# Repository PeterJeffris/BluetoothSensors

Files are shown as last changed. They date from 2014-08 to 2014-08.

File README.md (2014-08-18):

Background:
The goal of this project is to create an sensor platform wirelessly connected to a control and logging application on an android phone. The sensors include an accelerometer, a gyroscope, a combined barometer and temperature sensor and an ambient light sensor. The data is logged to the phones internal SD card or simply shown on the screen set with GUI configuration buttons on the android phone.

Software Development:
There are 3 collections of software developed for this project. The first is the java code for the android phone residing in the android folder. This code is intended to be compiled and uploaded to the phone using the android SDK package in the Eclipse IDE. This code contains a multithreaded android application that manages the display and configuration options in one group of threads and receives and processes and logs the data received over the Bluetooth radio connection in the other set.

The second collection of code is written in C++ and is used to run the Atmega328 chip that coordinates the collection of data from the sensors and is found in the AVR folder. This code is meant to be used with the wiring libraries and can be uploaded via the Arduino IDE or a build program such as scons or make. I2C driver libraries were written for this application to communicate with each of the sensors and are also included in this folder. Additionally there is a test script written in python that allows direct collection from the senor board by hooking up an FTDI cable to the Tx and Rx lines of the radio.

The final code is written in matlab and is used to determine the calibration coefficients for the relative alignment and scaling of the accelerometer and gyroscope. There are also several functions written to perform conversions between Euler angles which the gyroscope returns and rotation matrix and quaternion representations.

Hardware Development:
The circuit schematics and PCB layout are present in the hardware folder. These files are mean to be developed with the Eagle CAD software. The board itself is constructed as an Arduino compatible shield and matches directly with the pins on an Arduino board. Each of the sensors was purchased on breakout boards from sparkfun allowing for through hole construction techniques using chemically etched boards. 

A solder jumper had to be modified on the bottom of the gyroscope boards in order to change their output from SPI to I2C. Along with the gyroscope, the accelerometer and barometer also use the I2C communication protocol. Theses chips are placed on a single BUS with 3.3 Volt logic. This logic is then converted to 5 volt logic to the AVR processor using a level shifting circuit. The power supply utilizes 4 AA alkaline batteries whose voltage begins at 5.6 volts and drops to 4 volts at 4 discharge. The linear regulator supply filters and regulates this voltage at the cost of a 1 volt drop out. The AVR processor and radio are tolerant to the voltage changes down to the point where the batteries are operating at 4 volts. 

To configure the radio it must be connected to an FTDI cable. Open a serial terminal using the FTDI port (the arduino IDE serial monitor will also work if you select the FTDI port) and disable the line ending on output and send the string '$$$' (everything inside '' is entered and return is pressed). You will see the radio enter command mode by returning 'CMD' if you have done the setup correctly and the status light will blink at a faster interval. Then re-enable line endings and send the command 'SN,DEVICE_NAME' where DEVICE_NAME is what you want the bluetooth device name to be displayed as. Use the command 'SP,XXXX' to set the security pin where XXXX is the alphanumeric pin code to be entered upon connecting to the device from a phone. Use the command 'SU,XX' to set the baud rate where the XX is the first two characters of the baud rate (ie 11 -> 115000 bits per second). If this is done the corresponding baud rate in the AVR code also needs to be changed. To verify this information has been properly set use the 'D' command to display the basic settings. 

Features: 
The slides included in this repository describe the various features of the system and show the conclusions of the experimental trials utilizing the sensor.

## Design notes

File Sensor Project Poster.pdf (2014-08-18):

# Smartphone-Enabled Mobile Measurements

### Systems and IMU Research by Peter Jeffris Directed by Professor Y.C. Lee

## Overview

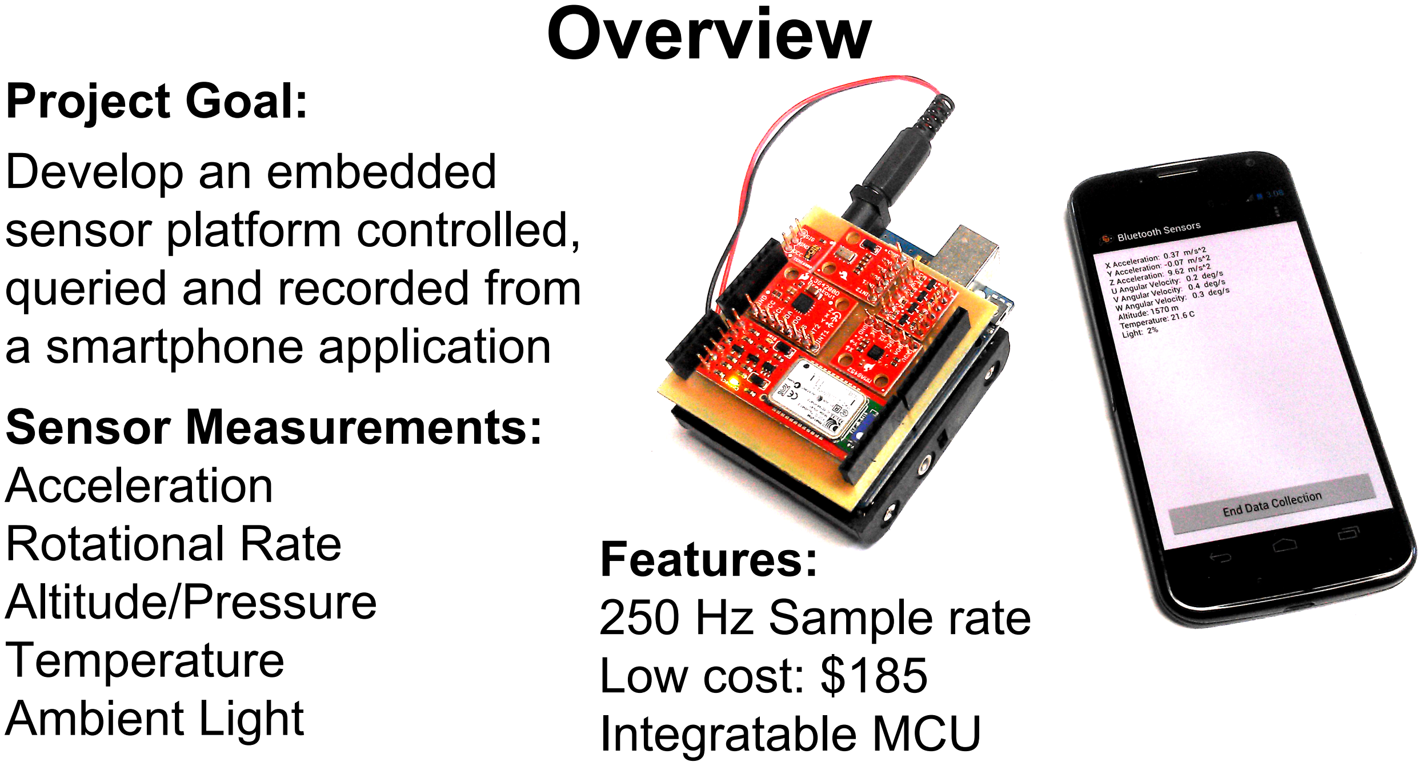
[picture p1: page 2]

Project Goal:
Develop an embedded
sensor platform controlled, queried and recorded from
a smartphone application
Sensor Measurements:
Acceleration
Rotational Rate
Altitude/Pressure
Temperature
Ambient Light

Features:
250 Hz Sample rate
Low cost: $185
Integratable MCU

## Systems Architecture

Logging Platform:
Motorola Moto X
running Android 4.4

Sensor Hardware:

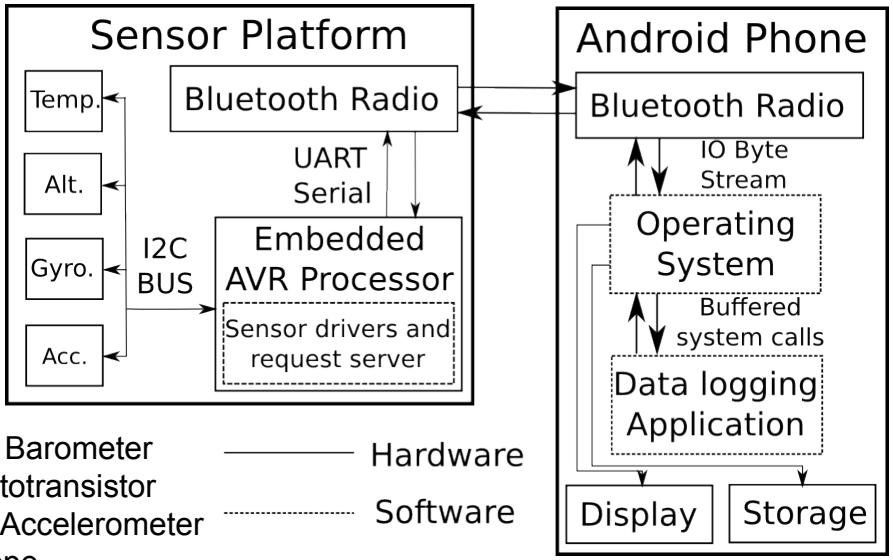
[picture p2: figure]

Freescale MPL3115A2 Barometer Vishay TEMT6000 Phototransistor Freescale MMA8452Q Accelerometer ST L3G4200D Gyroscope

Sensor Platform:
AVR microcontroller
and Arduino board
compatible sensor
shield powered by an
AA battery pack

## Android User Interface

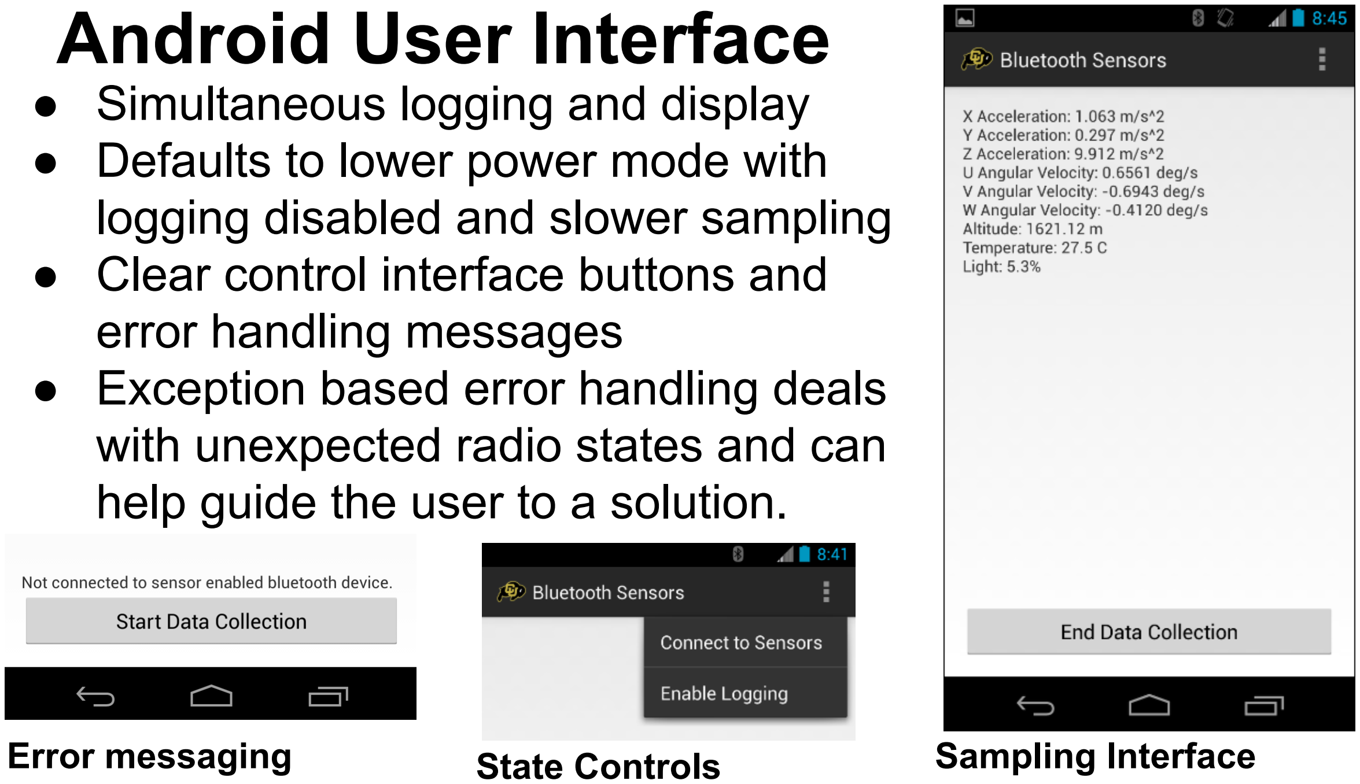
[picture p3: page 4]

- Simultaneous logging and display
- Defaults to lower power mode with logging disabled and slower sampling
- Clear control interface buttons and error handling messages
- Exception based error handling deals with unexpected radio states and can help guide the user to a solution.
Error messaging | State Controls | Sampling Interface

## Android Threading Methods

Multithreading:
Allows sensor data

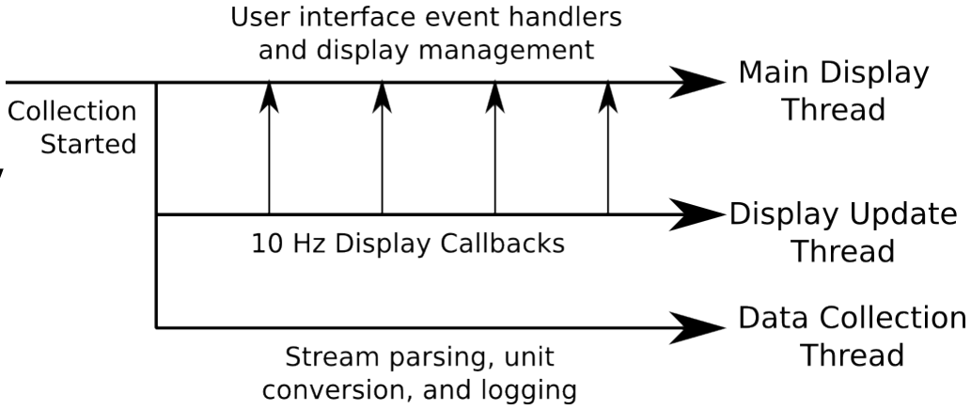
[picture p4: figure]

processing and display
synchronisation to be
handled by the
operating system
scheduler
This approach solves several problems:
1. Minimizing report latency and consistent display refreshing
2. Allows user interface to be responsive regardless of load
3. Reduces complexity of error handling and state changes

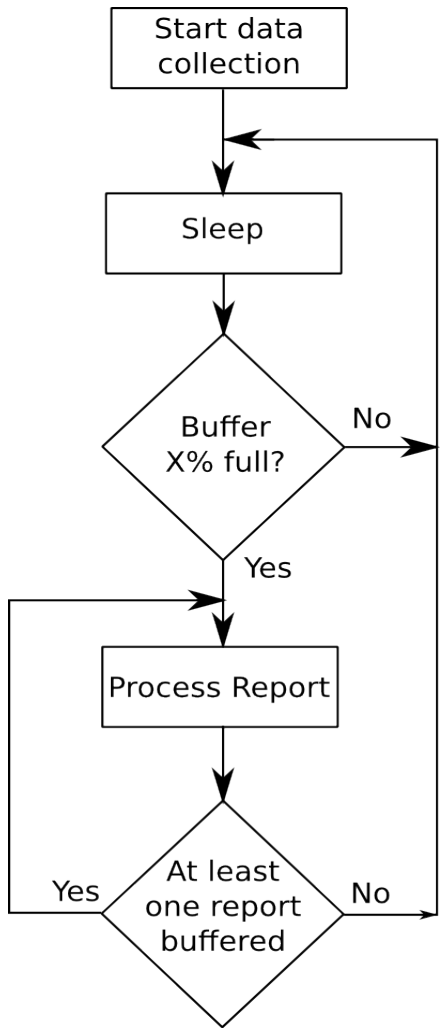
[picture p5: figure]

## Android Input/Output Methods

Buffered I/O Benefits:
- Reduced context switching overhead: Fewer system calls are required to read the stream
- Fast and efficient memory access: Large chunks of each memory page can be cached and processed quickly
Tuning:
- Single parameter for management of buffer overflow and report processing latency
- Buffer size set to maximize sampling with system memory and processing resources

## Networking Methods

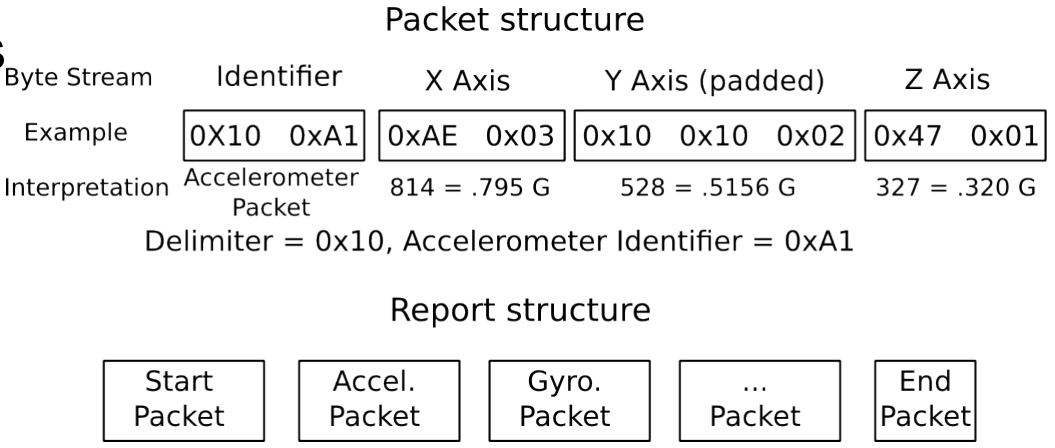
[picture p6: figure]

An single delimiter indicates a packet type while two delimiters indicates a payload byte that is identical to the delimiter itself

- Bluetooth Radio has
no QOS guarantees
- Packets structure
allows checking for
lost bytes, enabling
streaming reports
- Report Structure
simplifies correction
routine after a
corrupted packet

## Sensor Board Construction

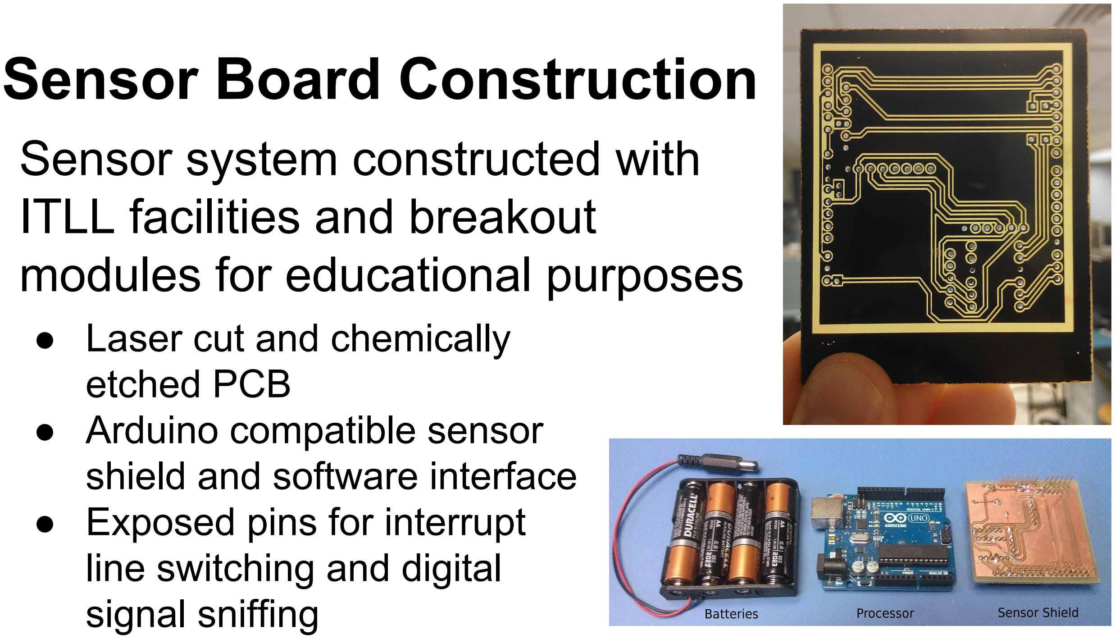
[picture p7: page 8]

### Sensor system constructed with ITLL facilities and breakout modules for educational purposes

- Laser cut and chemically
etched PCB
- Arduino compatible sensor
shield and software interface
- Exposed pins for interrupt line switching and digital signal sniffing

## Sensor Fusion

- Change in linear distance can be estimated by double
integrating acceleration with respect to time
- Gravity must be subtracted from the total acceleration and the result transformed into the earth’s reference frame
- The gyro is integrated to keep track of changes in attitude when the acceleration vector is greater than the gravity vector
- Information from both
sensors can be fused to
provide an estimate with
smaller uncertainty

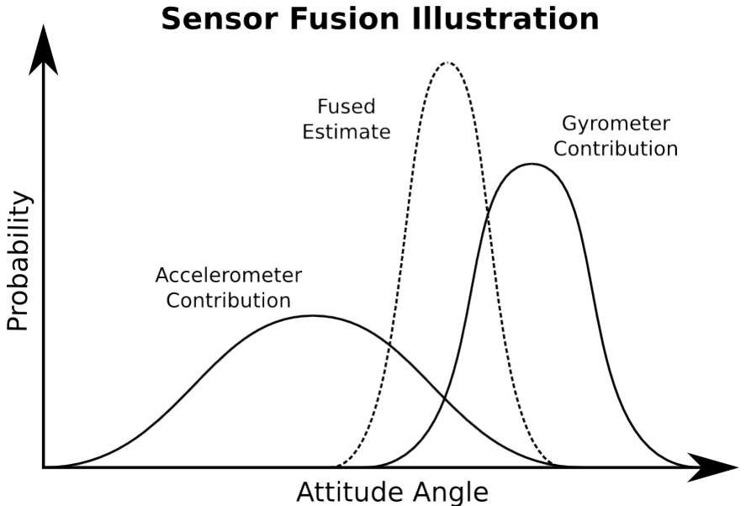
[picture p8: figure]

## Calibration and Filtering

Calibration Parameters

- Accelerometer and gyrometer reference frame alignment
- Accelerometer and gyrometer scale correction
- Accelerometer offset bias
Filtering Methods
- Kalman filtering optimally removes sensor noise from the position estimate
- Quaternion attitude representation prevents gimbal lock
- Runge-Kutta integration minimizes numerical integration error

Effective calibration and
filtering are required to
prevent integration drift

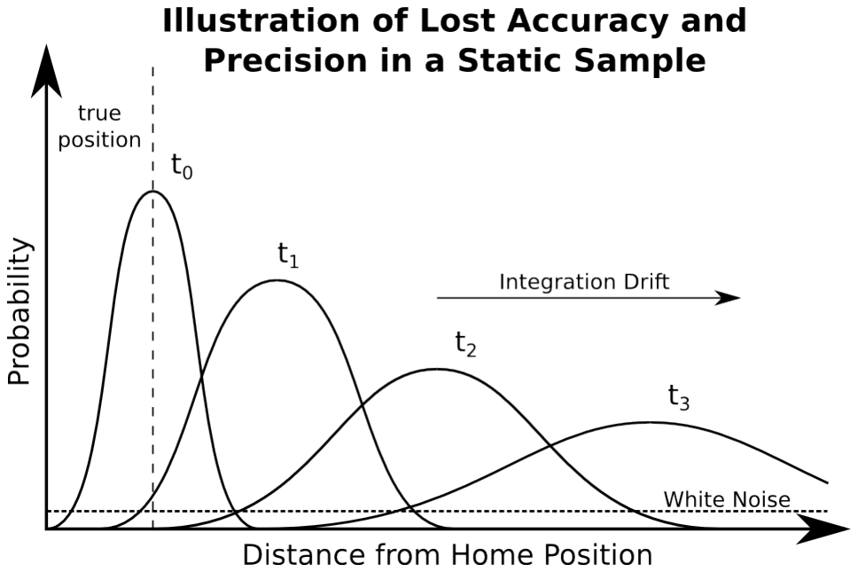
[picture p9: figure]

## Linear Testing

Test: Estimate of linear distance traveled

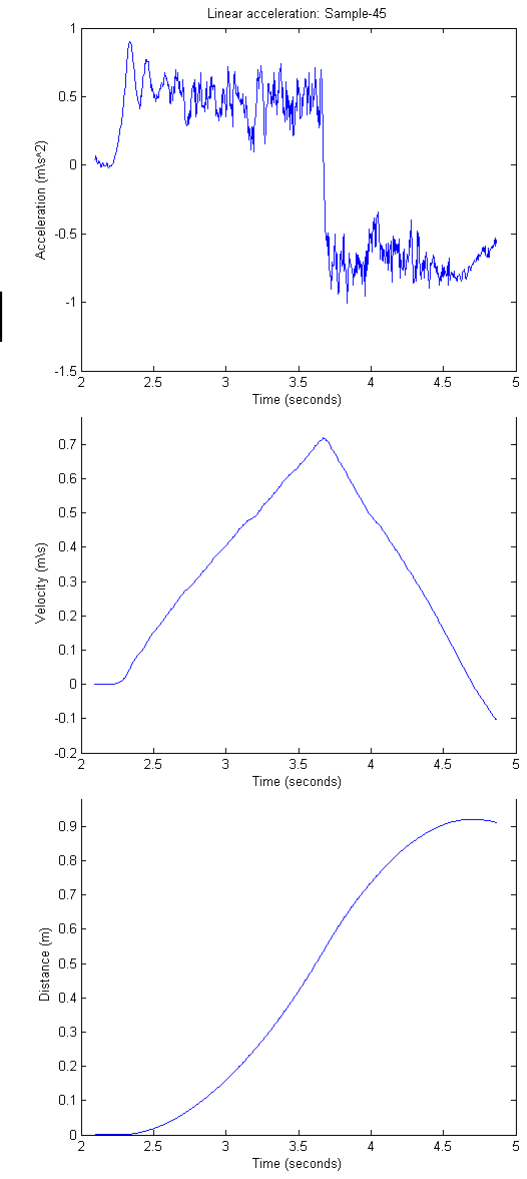
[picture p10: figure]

under step acceleration with simpsons method at various filter cutoff rates and sampling frequencies.
Results:
- Low pass filtering does not increase mean estimate accuracy
- Increased sampling speed increases mean estimate precision
- Bias offsets dominates the error if the sensors are not carefully calibrated

## Applications

Systems Integration

- Multitasked with other processes
- Real time motion analysis
- Live networked reporting
- Control system operation
- Example: Intel Galileo development board running a Linux OS

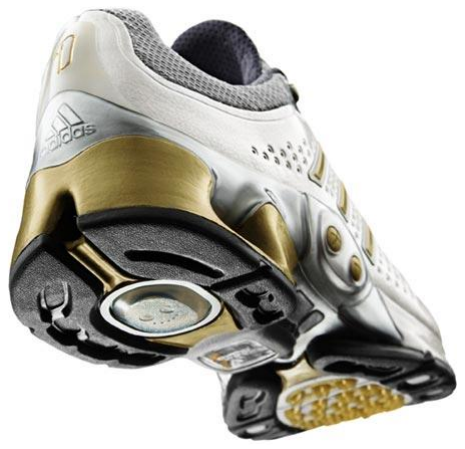
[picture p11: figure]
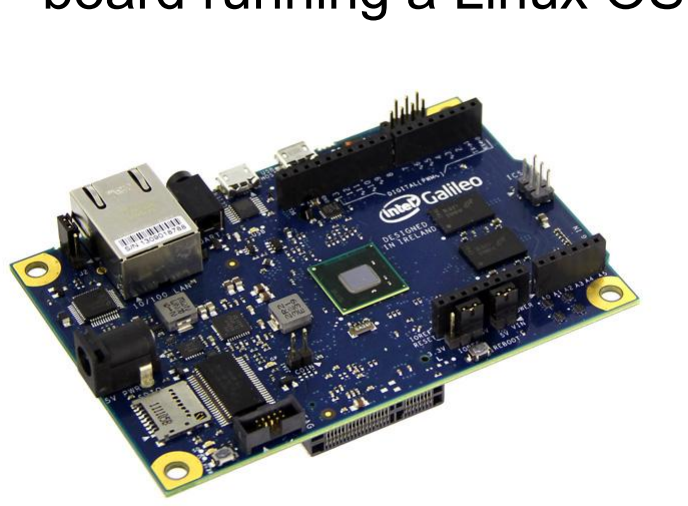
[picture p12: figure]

Embedded Sensors
- Wearable electronics
- Robot attitude
- Vehicle motion
- Slip detection

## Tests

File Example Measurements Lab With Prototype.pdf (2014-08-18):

# Position Estimation via Accelerometer Data

Introduction
Inertial sensors belong to a class of sensors that offer high precision indications of changes in kinematic state over short time periods. Other systems like GPS and GSM triangulation can offer relatively high accuracy in position but do not have high precision. Measurements of changes in the inertial frame of micromechanically machined capacitive sensors can be used to infer changes in position and in conjunction with the other location mechanisms can be used to achieve a highly precise and accuracy location mechanism. The application of numerical integration and gravity filtering techniques are critical to leveraging the inertial sensors accuracy. Using a sensor platform to record acceleration and angular rate, this lab will investigate the effects on filtering and sample rate on position estimates inferred from the inertial measurements.

Initial Tests
The main obstacle for obtaining position estimates from acceleration data is removing the effects of integration drift. Small bias in the acceleration data doubleintegrates large changes in position, even for stationary sensors. An obvious bias is gravity, which acts -9.8 1 constantly in the zdirection. Other
s

2

m
biases include zeromean signal noise in the acceleration data which develop a nonzero bias when digitally sampled. Several three dimensional test were performed in which the gravitational bias and initial orientation of the sensors with respect to gravity was found in a calibration period. The gyro and accelerometer measurements were then fused utilizing a rotation matrix to find the acceleration in gravities reverence frame. It was found that small errors in the estimate of the orientation caused by drift in the gyro resulted in large nonlinear drift in the acceleration due to the estimated orientation of the sensors being misaligned with gravity. This misalignment caused components of the gravity offset to be subtracted from the wrong axes resulting in steady state error in the perceived acceleration. Once this error was integrated twice large errors in position an order of magnitude large than actual movement were observed.

Experimental Setup
Since bias error corrupts the acceleration data, a repeatable experiment is implemented in order to analyze the errors and statistically predict which sampling frequencies and lowpass filtering produce the most accurate data. Our repeatable setup explores prediction accuracy with one dimensional stepped constant acceleration.

TABLE 1: EXPERIMENTAL FACTOR LEVELS

Factors | Lowpass filter cutoff | Sampling Rate
Level 1 | 20 Hz | 500 Hz
Level 2 | 10 Hz | 250 Hz
Level 3 | Infinite | 125 Hz

A linear rail isolates motion of the sensor to a single axis, see Figure 5. A lowfriction cart, with the sensor clamped onto it, accelerates constantly by a falling bolt which is tethered to the cart by a string. The track is slightly inclined so there is a period of constant acceleration while the bolt falls and another period of constant acceleration in the opposite direction after the bolt hits the ground, see Figure 6. Before each trial, the cart is left still to record calibration data of the components of gravity present in each sensor axis. The sensor platform logs the values to delimited file via a serial connection. The experiment has two factors: hardware lowpass filter cutoff frequency and sampling frequency with three levels each as seen in Table
1. Each treatment application is randomly applied in order to minimize a consistent effects from uncontrollable factors.

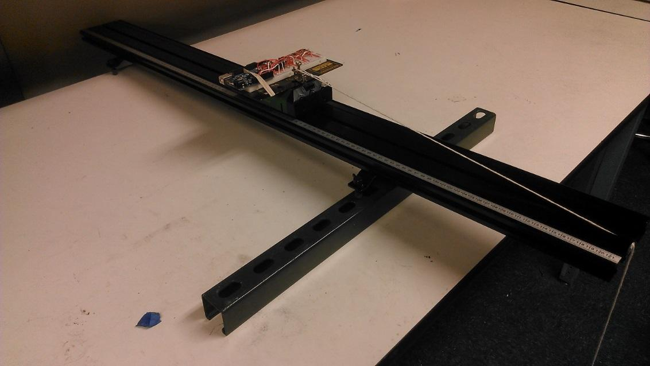
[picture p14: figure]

FIGURE 1: LINEAR RAIL EXPERIMENTAL SETUP

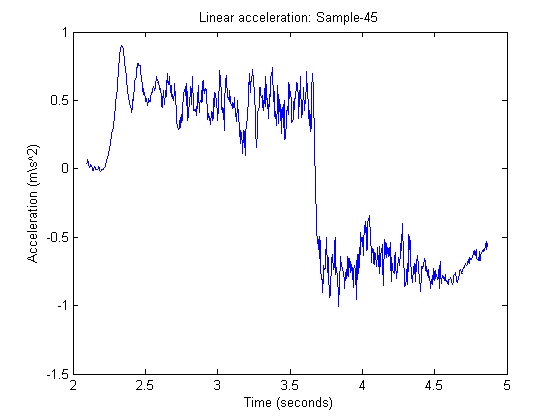
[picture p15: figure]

FIGURE 2: SAMPLED CONSTANT ACCELERATION AND DECELERATION

Materials
MMA8452Q 3-Axis Accelerometer | Arduino Uno
Breadboard and Wiring | Weight
Low-Friction Track (120cm) | Twine
Low-Friction Cart | Matlab
Clamp | Temperature sensor

Trial Procedure
A sensor board is constructed with a MMA8452Q 3-Axis accelerometer on an I2C bus connected to an 8 bit Atmel 328 microcontroller. Data is relayed from the sensor to a computer via a USART serial connection and stored in a csv format with each accelerometer axis as produced by the on board analog to digital converter and the time recorded between samples in microseconds. The cart is first placed on an inclined track and the sensor board is clamped down to the cart. The initial temperature is recorded and the position of the front of the cart is measured from the linear scale on the track to +/.5mm.
Acceleration of the cart is achieved by attaching a string between the cart and a weight. When the weight is dropped it would overcome gravity and accelerate until it hit the ground ending the forward acceleration step. Then gravitational acceleration would cause a step of negative acceleration for the remainder of the test. A piece of paper folded into a triangle is placed 3 centimeters before the predicted end point along the scale as seen in Figure 8. The cart would hit this triangle and push it up to the maximum distance, from which the actual maximum distance traveled could be found to a precision of +/.5mm. For each test a small calibration is performed with a three second delay, then the weight is moved near to the point where it would start supporting the weight of the cart and dropped. When the cart has reached its maximum distance traveled it is allowed to slide back for a second before being caught and ending data collection.

The treatments are applied randomly based on ordered numbers generated by a computer pseudo random number generator in Matlab. At the end of the test the temperature is measured again.

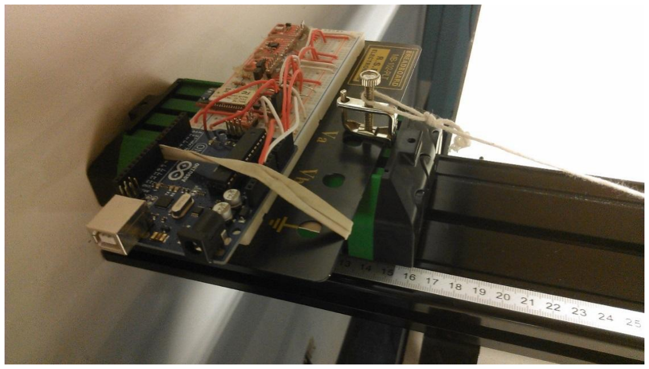
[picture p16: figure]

FIGURE 3: ACCELERATION MODULE SETUP

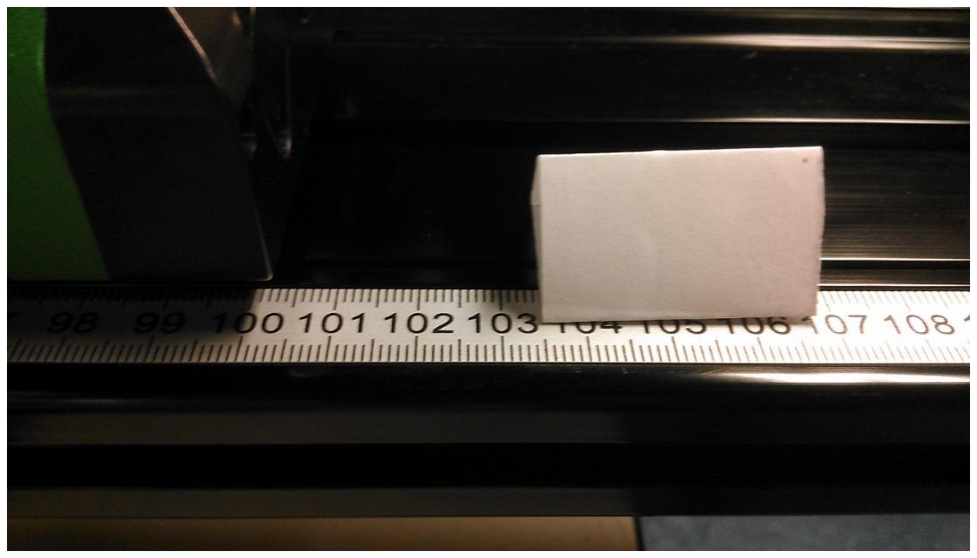
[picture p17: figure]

FIGURE 4: CART APEX OF TRAVEL

Analysis
The data is imported into a numerical analysis program and integrated with time using the trapezoidal method in order to estimated velocity, the velocity is again integrated to estimate the change position. The force of gravity is determined from the calibration data at the beginning of each sample by taking the sum of the squares of the component in each axis defined by the mean of each axis results during the calibration period and dividing by the true gravitation constant. The components of gravity and sensor bias are removed by subtracting the mean values recorded during the calibration period from each axis. The start and end times of the data are numerically determined from the beginning and end of positive velocity in a first pass estimate and buffered on each side with a constant additional time. The acceleration data is then reintegrated over these times to reduce drift errors due to inconsistent delays before release. The resulting velocity data is seen in Figure 9.

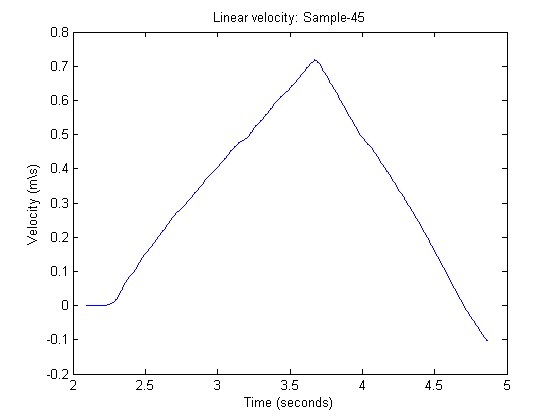
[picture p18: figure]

FIGURE 5: ESTIMATED VELOCITY

The position is extracted from this data by finding the maximum estimated distance reached. Using this data and the measured true distances traveled the relative errors are then computed. The relative errors are then tested for normality, equality of variance, and equality of means within Matlab.

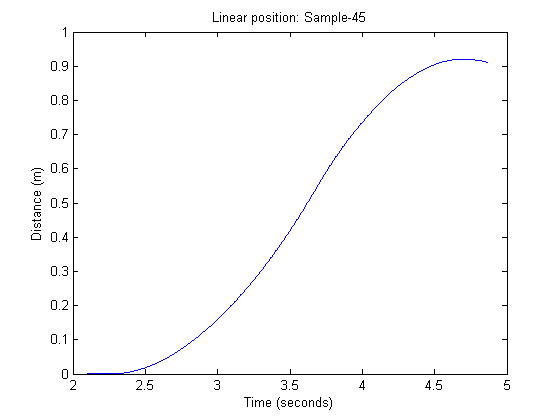
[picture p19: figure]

FIGURE 6: ESTIMATED POSITION

Error
The measured error of this experiment derives from the difference between the estimated and actual maximum distance travelled, normalized by the actual distance travelled.
error = | distancemeasured
|distance | −distance | | estimated | measured

The measured error is calculated using estimated difference determined between the start and maximum estimated position and subtracted from the true distance traveled and then divided by the true distance traveled to arrive at the relative error.

The main quantifiable sources of error occurs as products of the experimental setup and sensors limitations. The experimental setup errors includes uncertainty in the alignment of the accelerometer axis with the axis of motion, error in keeping the alignment constant after the calibration and error in the measurement of actual distance traveled. The sources of error in the sensor measurements include error due to temperature change, discretion error, and sensor error due to inaccuracies in the MEM sensors and amplifiers due to nonlinearity, electrical noise, and sensor sensitivity. The sensor measurement errors have to be integrated over all time with the mean acceleration and sampling period in order to find their effect. Also the integration errors depend on an uncertainty in the sampling period and their rate of change with respect to this uncertainty must also take into account. The sum of the squares of all of these error produce the theoretical uncertainty of the experiment as shown in the equations below.

The average magnitude in acceleration is about aoutput = .75 , the average sampling rate is dependent on s
2

m
the sampling rate applied to the treatment. The average value of gravity is taken at to beG = 9.81 m/s ,

2
the number of bits in the DAC isn = 10 . The sampling rate report time is recorded in microseconds based on the time between the start of sensor request times with a resolution of a microseconds producing an
f | Hz. The alignment error in the track affecting calibration is measured to be about sampling = 10

6
αtrack = 2% . The alignment of the sensor on the cart is estimated at αcart = 3% . The temperature at the start of the test is 23.5 C and the temperature at the end of the test is taken at 22.0 C. The uncertainty in the measurement of the scale is half the size of the scale divisions u .5 mm. The resulting theoretical scale = uncertainty at the maximum sampling rate is approximately 10 cm. Because the measured values are within a factor of 2 of the theoretical uncertainties, it is reasonable to conclude that there were no other factors that caused effects in the result. It is reasonable to assume that in reality a large portion of this error would cancel out where as the theoretical estimate assumes it is at its maximum value.

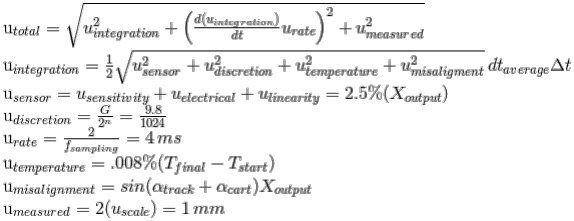
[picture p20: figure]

The major random source of error affecting the experiment is the initial carttrack alignment. The component of gravity removed during the calibration could be partially reintroduced once the cart began to move and during its path down the track. This error is amplified during the integration showing up as a constant velocity bias. Because the cart could not easily be aligned at the beginning of each test beyond the angles constrained by the track, this parameter could change with each sample. The major constant source of error is the alignment of the sensor with the track path. This alignment is consistent throughout the test due to the fixed nature of the board on the cart.

### Results

The results below indicate a consistent negative bias in the mean relative error. This was attributed to imperfect alignment of the sensors with the axis of motion. These components cannot easily be integrated back into the accelerations with an accuracy less than their magnitude due to imperfections of the alignment of the cart on the track. For this reason a second test was not performed taking into account these additional axes. One noticeable pattern in the data is a smaller variation in the data at the maximum sampling rate and larger variation in the reduced sampling rates at 250 Hz and 125 Hz. Observation of these trends was used to design tests for the significance of any effects caused by the two factors.

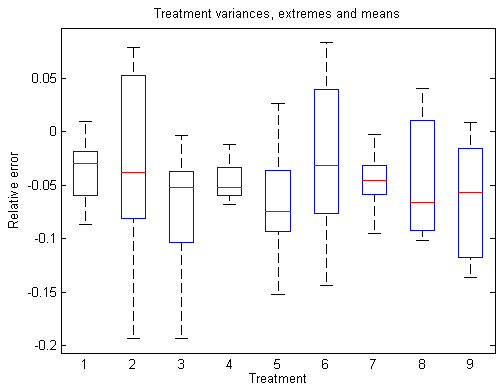
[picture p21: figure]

Filter Cutoff | 20 Hz Low-Pass | | | 10Hz Low-P ass | | | No Low-P ass
Sampling Rate | 500Hz | 250Hz | 125Hz | 500Hz | 250Hz | 125Hz | 500Hz | 250Hz | 125Hz
Treatment | 1 | 2 | 3 | 4 | 5 | 6 | 7 | 8 | 9
| -2.05 | -2.48 | -0.35 | -6.27 | -8.26 | -3.32 | -3 | 0.92 | -3.54
| -6.58 | 4.1 | -8.61 | -6.83 | -15.21 | 0.61 | -6.08 | -10.14 | -12.49
| 0.92 | 7.88 | -2.74 | -5.63 | 2.62 | -3.38 | -3.25 | -9.19 | 0.86
| -5.36 | -19.31 | -4.96 | -5.22 | -9.04 | -14.43 | -4.12 | 4.01 | 0.43
| -8.67 | -9.13 | -12.15 | -1.17 | -4.48 | 8.3 | -0.25 | -4.21 | -10.97
| -17.5 | -7.19 | -19.29 | -2.36 | -9.59 | 7.27 | -5.66 | -9.04 | -13.66
| -3.67 | 6.43 | -5.48 | -5.29 | -6.73 | -11.88 | -4.95 | 1.24 | -6.58
| -2.21 | -5.11 | -4.65 | -4.38 | -2.78 | -3.1 | -9.54 | -9.36 | -4.87

Mean Error | -3.67 | -3.10 | -7.28 | -4.64 | -6.68 | -2.49 | -4.61 | -4.47 | -6.35
95% C.I. | 2.50 | 7.44 | 4.91 | 1.59 | 4.31 | 6.56 | 2.21 | 4.70 | 4.58

Analysis
The histogram of the relative errors in each treatment indicates good evidence that they come from normally distributed populations. The samples are compared with different bin sizes which revealed a general trend of more frequent occurrences centered near the mean of the sample and less frequent observations occur near the tails. The treatments missing tails on one side can be accepted because they show approximately normally distributed behavior with chance occurrences in the edge bins that do not clearly suggest skewed parent population distributions.

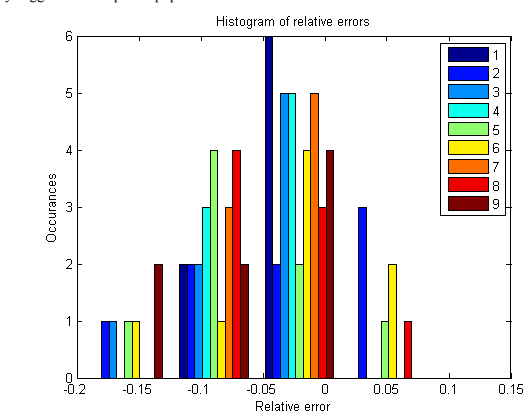
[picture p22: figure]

FIGURE 7: HISTOGRAM OF RELATIVE ERROR

From the justification of the normality assumption it is possible to run Bartlett’s tests with the hypothesis that the sample of each treatment comes from a normal distribution with the same variance, against the alternative that they come from normal distributions with different variances. P represents the probability of observing the samples taken, or ones more extreme, by chance if the null hypothesis of equal variances is true. Small values of P indicate that there is low probability that the variances could be as observed by chance if they are really the same.

Bartlett’s variance test | P-value
All treatments | 0.3%
Maximum sampling rate | 62.5%
Reduced sampling rate | 51.1%

These test results indicate that the variances of all treatments cannot be considered to be equal with 95% confidence. Tests of the samples treated by reducing the sampling rate indicates that the hypothesis that their variances are equal cannot be rejected with greater than 95% confidence. Similarly tests of the samples treated by sampling at the maximum possible rate suggests that the hypothesis that the samples have the same variance should not be rejected.

With the knowledge of the treatments with equal variance tests of the hypothesis that the samples come from normally distributed populations with the same variance and mean can be tested against the alternative hypothesis that they come from normally distributed populations with the same variance but different means. P represents the confidence with which the null hypothesis should not be rejected.

The first test utilized a single factor ANOVA to test for the difference in means for the maximum sampling rate treatments. The levels consisted of the different lowpass filter cutoff frequencies.

Single factor ANOVA | Filter level
P-value | 70.5%

The result of this test indicates that the hypothesis that the means of the relative error are unaffected by the low pass filter cannot with greater than 95% confidence. A graphical description of the data used in this test shown below indicates the mean with a red line, the populations maximum extent with a black line, 95% confidence intervals at the intersection of the oblique and vertical blue lines, and the 75% percentile of the data with the horizontal blue lines.

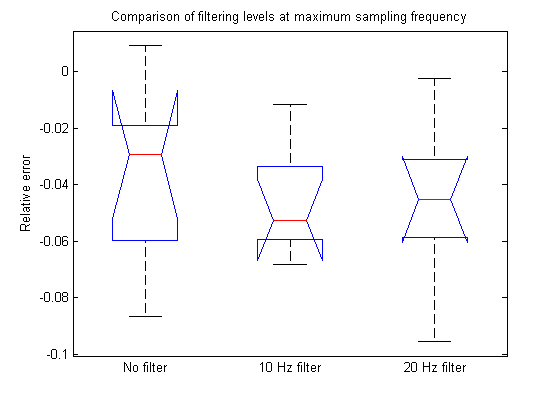
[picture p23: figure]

FIGURE 8 : 500 HZ SAMPLES AT VARIOUS FILTERING LEVELS

The second test is formulated as a two way ANOVA test of the hypothesis that the means of the down sampled tests (250 and 125 Hz) come from normally distributed populations with the same variance and mean against the alternate hypothesis that they came from normally distributed populations with equal variance but different means.

Two factor ANOVA | Sampling level | Filter level | Interaction
P-value | 75.3% | 93.9% | 21.0%

This test suggests that there is no reason to reject hypothesis that the means are unaffected by either lowpass filter cutoff frequency or sampling rate for sample rates below the maximum sampling rate. At the sampling level and the filter level there are very high probabilities that the difference in the means could happen by chance, and although the probability that there is an interaction is much lower, it is above the critical level required to say that the hypothesis that there is no effect should be rejected. The data is shown in a separated form in figures 9 and 10 which help reveal why this is the case.


FIGURE 9: EXPERIMENTAL RELATIVE ERROR RESULTS

FIGURE 10: COMPARISON OF REDUCED SAMPLING RATE POPULATIONS

The final analysis gains insight from a Welches ttest with the hypothesis that the samples from the maximum sampling rate treatment come from the same normally distributed population as the samples from treatments with the lower sampling rates against the hypothesis that they do not come from normally distributed populations with equal means. This test only relies on the normality assumption and takes into account the different variances and sample sizes of the combined samples.

Welche's ttest | Equal means
P-value | 59.1%

The result is that there is little reason to doubt the hypothesis that the means of the 500 Hz samples come from a population with the same mean as the 250 and 125 Hz samples. The conclusion is that neither sampling rate nor filtering cutoff rates have an effect on the mean of the populations.

Conclusions
The data indicates that it is unlikely that there is a difference in the mean relative error in estimated distance as a result of either low pass filtering at various rates or sampling at lower rates under the tested conditions. The analysis suggests that it is possible that there is a significant difference in the variance of the maximum sampling rates and reduced sampling rates although there is not enough evidence to doubt the conclusion that the variance of either of the two reduced sampling rates are different. Considering approximately linear relationship in computational with sampling capability, the results suggest that if the variance of the estimated relative error in position is not important, a slower sampling rate without filtering should be chosen to reduce cost. If a smaller variance in the relative estimated error is required sampling should be performed as quickly as possible without filtering post processing. These suggestions only are valid under the experimental conditions used in this test, future tests should be set up to examine effects from different smoothness, duration and complexity of linear motion in conjunction with changes in sampling rate before exploring other noise reduction techniques.

Cost Justification
Low cost microcontrollers such as the AVR architecture processors can cost $1.75 in bulk quantities whereas faster ARM architecture chips cost around $5.50 in bulk. Both chips can achieve 2-3 cycle multiplications for their word size, but the ARM design with average maximum clock speeds of 120 MHz and 32 bit registers can achieve roughly 12 times the computational throughput as the 16 MHz average maximum AVR chips (8 bit registers for a 16 bit number). By decreasing the computational overhead required for processing sensor data by a factor of 15, cost is reduced by a factor of 3. The complexity of sampling faster requires more overhead to the context switch to keep up with the other responsibilities of the processor, so the ultimate complexity of sampling increases at a similar rate. This lowers the sampling rate and aligns the cost more linearly with the computational overhead required.

Discussion of Future Experiments
The primary purpose of applying the different treatments is to find ways to better overcome the noise sources inherent to motion in an inertial reference frame. The main sources of noise are in the experiment used are:
1. High frequency signals due to imperfections in the track rails and wheels in addition to noise introduced by the power supply (~100 Hz).
2. Medium frequency noise due to the massspring damper system created by the weight connected by a partly elastic string (~10 Hz).
3. Low frequency noise resulting from the cart wheels ricocheting of the side of the rails due to misalignment (~1 Hz).
This massspring damper noise has the largest magnitude of the 3 because it is aligned purely with the axis of motion. The friction of the string on the end of the rail is small and the resulting system is underdamped so these oscillations exist for some time during the positive acceleration portion of the measurement. It is expected that these oscillations could be fully integrated by the sensors due to their relatively slow frequency and thus do not constitute a problem for the sensors. The low frequency noise due to the misalignment cannot be corrected by any of the methods currently used in the experiment and require sensor fusion with a gyroscope and statistical filtering techniques such as the Kalman filter to eliminate them.
The first noise source is the primary target of the methods used in this experiment. Since they are on the same order of the sampling rate, a significant portion of the high frequency signals will occur above the Nyquist frequency, resulting in aliasing effects and random error offsets dependent on the magnitude of the noise. It was expected that the low pass filtering would help reduce the uncertainty introduced to the integration by these high frequency signals but the results indicate that this can only be accomplished with an increase in the sampling rate. One likely explanation for this is that digital filtering of the already aliased signal cannot reduce the bias offset because it has been irreversibly added to the system. Therefore the intuition that led to the hypothesis in the first place may still be valid in the case that low pass filtering is applied before the analog to digital conversion in hardware.

Future experiments should explore the application of sensor fusion for controlled movements. It was discovered in this experiments conducted prior to this one that drift due to simple sensor fusion algorithms dominate the overall error in position. The best use of resources would be to first try to get accurate results from an improved algorithm such as the Kalman Filter which takes into account knowledge of the variance of the sensor measurements to make an estimate of position that can be weighted with its probability of being seen only due to noise effects before being integrated. Using these methods it is expected the relative error can be centered on zero, and then further improvements in faster sampling accelerometers and gyros with hardware filtering can be used to improve the variance of position estimates up to a limit defined by noise due the power supply and the physical accuracy of the sensors.

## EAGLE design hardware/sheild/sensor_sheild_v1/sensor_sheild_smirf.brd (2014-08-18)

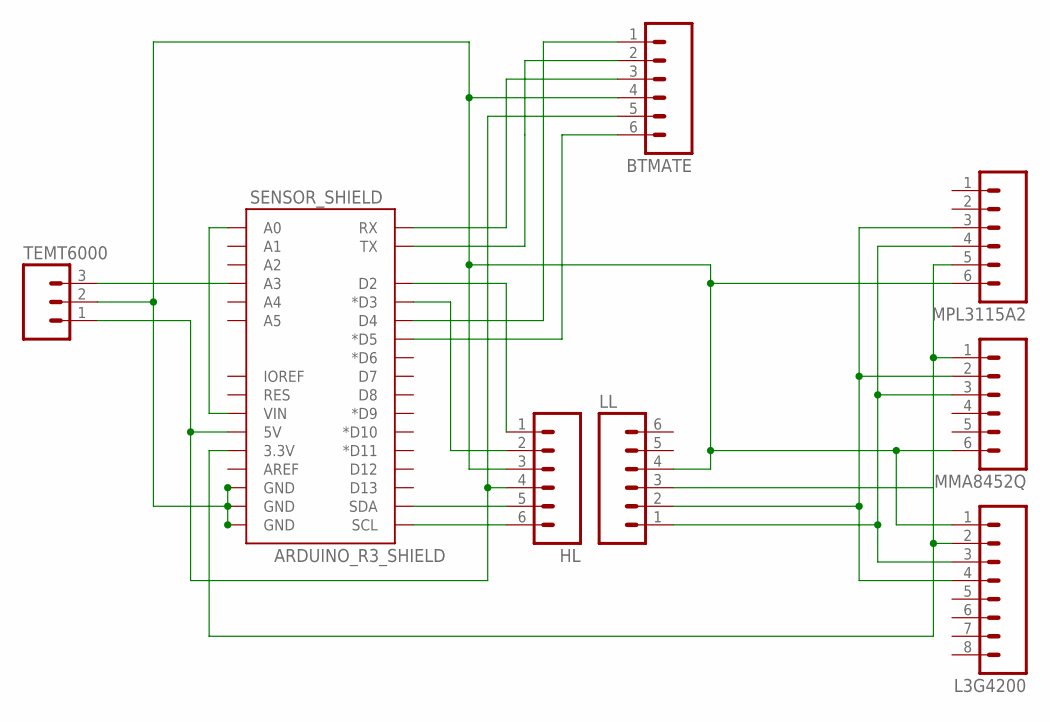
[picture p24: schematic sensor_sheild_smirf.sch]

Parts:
BTMATE: M06NO_SILK; 1X06_NO_SILK
HL: M06SIP; 1X06
L3G4200: M08; 1X08_PIN1_NO_SILK
LL: M06SIP; 1X06
MMA8452Q: M06SIP; 1X06
MPL3115A2: M06SIP; 1X06
SENSOR_SHIELD: ARDUINO_R3_SHIELD; UNO_R3_SHIELD
TEMT6000: M031X03_NO_SILK; 1X03_NO_SILK

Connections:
GND: BTMATE.4, HL.3, L3G4200.1, LL.4, MMA8452Q.6, MPL3115A2.6, SENSOR_SHIELD.GND@0 (GND), SENSOR_SHIELD.GND@1 (GND), SENSOR_SHIELD.GND@2 (GND), TEMT6000.2
unnamed: SENSOR_SHIELD.A0, SENSOR_SHIELD.VIN
unnamed: BTMATE.2, SENSOR_SHIELD.TX
unnamed: BTMATE.3, SENSOR_SHIELD.RX
unnamed: BTMATE.1, SENSOR_SHIELD.D4
unnamed: BTMATE.6, SENSOR_SHIELD.D5 (*D5)
unnamed: L3G4200.4, LL.2, MMA8452Q.2, MPL3115A2.3
unnamed: HL.2, SENSOR_SHIELD.D3 (*D3)
unnamed: HL.1, SENSOR_SHIELD.D2
unnamed: L3G4200.3, LL.1, MMA8452Q.3, MPL3115A2.4
unnamed: HL.5, SENSOR_SHIELD.SDA
unnamed: BTMATE.5, HL.4, SENSOR_SHIELD.5V, TEMT6000.1
unnamed: L3G4200.2, LL.3, MMA8452Q.1, MPL3115A2.5, SENSOR_SHIELD.3.3V
unnamed: HL.6, SENSOR_SHIELD.SCL
unnamed: SENSOR_SHIELD.A3, TEMT6000.3

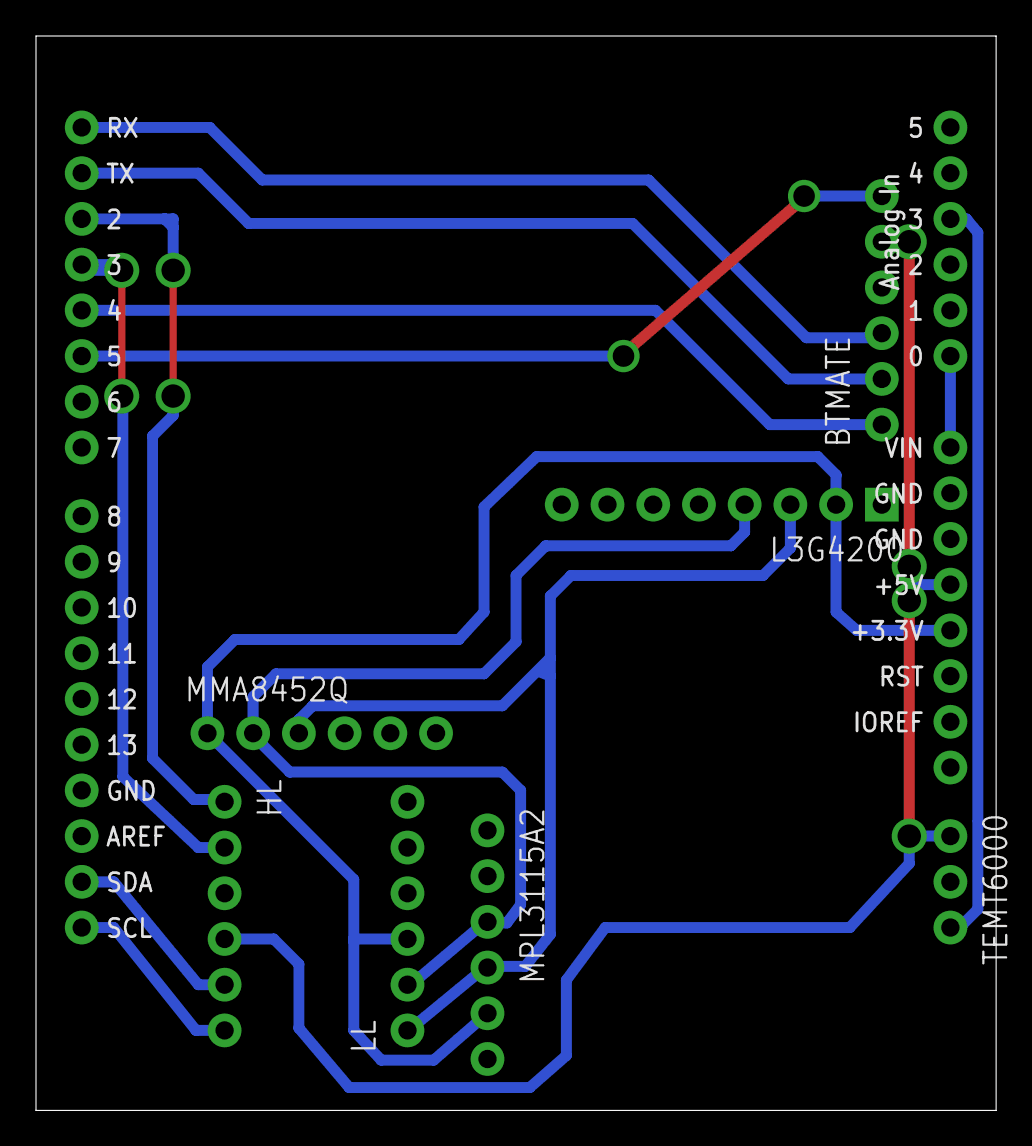
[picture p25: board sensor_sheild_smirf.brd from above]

Board: 2 copper layers, 53.3 x 59.7 mm, 8 parts (0 on the bottom side), 15 nets.

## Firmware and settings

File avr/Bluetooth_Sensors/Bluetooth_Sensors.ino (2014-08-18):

// Writen by Peter Jeffris, University of Colorado Mechanical Engineering
// Module to collect data from various sensors and respond to bluetooth
// requests for that data.

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
#define DEBUG 0

// Include sensor comunication and configuration libraries 
#include "MMA8452Q_Accelerometer.h"
#include "MPL3115A2_Barometer.h"
#include "L3G4200D_Gyroscope.h"

// Include I2C Library
#include "Wire.h"

// Comunication codes
enum network
{
    START_STREAM = 0xB0,
    END_STREAM = 0xB1,
    SEND_SINGLE = 0xB2,
    DLE = 0x10,
    STX = 0x20,
    ETX = 0x30,
    ACC = 0x01,
    GYRO = 0x02,
    BARO = 0x04,
    PHT = 0x08
};

// Error handeling codes
#define NO_ERROR 0
#define BUFFER_SIZE_ERROR 1
#define ADDRESS_NO_ACKNOWLEDGE 2
#define DATA_NO_ACKNOWLEDGE 3
#define TWI_ERROR 4
#define IDENTIFICATION_FAILURE 5

// Initialize the sensor objects
MMA8452Q_Accelerometer accelerometer;
L3G4200D_Gyroscope gyrometer;
MPL3115A2_Barometer barometer;
unsigned int ambient_light;
#define PHOTO_SENSOR_PIN A3

// Request code byte to be recieved by the 
char request;
// Error code resulting from I2C comunication
byte error;

// Timing variables
unsigned int start,stop,diff;
// Downsampling counter for the barometric sensor
short int sample_count;

// Initialize the sensors and serial objects
void setup()
{
    // Setup a hardware serial connection
    Serial.begin(115000);
    // Serial.print("Started serial\n");
    // Wire.begin();
    // Serial.print("Started i2c\n");
    // byte reg_value;
    // byte error = readRegister(0x60, 0x0C, reg_value);
    // Serial.print("Read identity\n");
    // Serial.print(reg_value,HEX);
#if DEBUG
    Serial.print("Starting setup\n");
#endif
    // Initialize the sensors on the I2C bus
    error = accelerometer.setup();
    if (error != NO_ERROR)
    {
#if DEBUG
	Serial.print("Accelerometer setup error: ");
	Serial.print(error);
	Serial.println();
#else
    while(true) {}
#endif
    }
#if DEBUG
    else
	Serial.print("Setup Accelerometer\n");
#endif

    error = gyrometer.setup();
    if (error != NO_ERROR)
    {
#if DEBUG
	Serial.print("Gyrometer setup error: ");
	Serial.print(error);
	Serial.println();
#else
	while(true) {}
#endif
    }
#if DEBUG
    else
	Serial.print("Setup Gyrometer\n");
#endif

    error = barometer.setup();
    if (error != NO_ERROR)
    {
#if DEBUG
	Serial.print("Barometer setup error: ");
	Serial.print(error);
	Serial.println();
#else
	while(true) {}
#endif
    }
#if DEBUG
    else
	Serial.print("Setup Barometer\n");
#endif
    start = millis();
}

void getData()
{
#if DEBUG
    error = accelerometer.readData();
    if (error != NO_ERROR)
    {
	Serial.print("Accelerometer communication error: ");
	Serial.print(error);
	Serial.println();
    }
    error = gyrometer.readData();
    if (error != NO_ERROR)
    {
	Serial.print("Gyro communication error: ");
	Serial.print(error);
	Serial.println();
    }
    if (sample_count == 0) {
	error = barometer.readData();
	if (error != NO_ERROR)
	{
	    Serial.print("Altimeter communication error: ");
	    Serial.print(error);
	    Serial.println();
	}
	ambient_light = analogRead(PHOTO_SENSOR_PIN);
    }
#else
    accelerometer.readData();
    gyrometer.readData();
    if (sample_count == 0) {
	barometer.readData();
	ambient_light = analogRead(PHOTO_SENSOR_PIN);
    }
#endif
}



void print_data() {
    getData();
    ambient_light = analogRead(PHOTO_SENSOR_PIN);
    stop = micros();
    diff = stop-start;
    start = stop;
    Serial.print(accelerometer.acc[0]);
    Serial.print(',');
    Serial.print(accelerometer.acc[1]);
    Serial.print(',');
    Serial.print(accelerometer.acc[2]);
    Serial.print(',');
    Serial.print(gyrometer.gyro[0]);
    Serial.print(',');
    Serial.print(gyrometer.gyro[1]);
    Serial.print(',');
    Serial.print(gyrometer.gyro[2]);
    if (sample_count == 0) {
	Serial.print(',');
	Serial.print((float)barometer.pressure+(float)barometer.pressure_frac/16);
	Serial.print(',');
	Serial.print((float)barometer.temperature+(float)barometer.temperature_frac/16);
	Serial.print(',');
	Serial.print(ambient_light);
    }
    Serial.print(',');
    Serial.print(diff);
    Serial.print('\n');
}

// Send sensor packets via bluetooth
void bluetooth_send() {
    getData();
    stop = micros();
    diff = stop-start;
    start = stop;
    Serial.write(DLE);
    Serial.write(STX);
    if (highByte(diff) == DLE)
	Serial.write(DLE);
    Serial.write(highByte(diff));
    if (lowByte(diff) == DLE)
	Serial.write(DLE);
    Serial.write(lowByte(diff));

    Serial.write(DLE);
    Serial.write(ACC);
    accelerometer.sendData(Serial,DLE);

    Serial.write(DLE);
    Serial.write(GYRO);
    gyrometer.sendData(Serial,DLE);

    if (sample_count == 0) {
	Serial.write(DLE);
	Serial.write(BARO);
	barometer.sendData(Serial,DLE);

	Serial.write(DLE);
	Serial.write(PHT);
	if (lowByte(ambient_light) == DLE)
	    Serial.write(DLE);
	Serial.write(lowByte(ambient_light));
	if (highByte(ambient_light) == DLE)
	    Serial.write(DLE);
	Serial.write(highByte(ambient_light));
    }
    Serial.write(DLE);
    Serial.write(ETX);
}

void loop() {
    sample_count = 0;
    start = micros();
    for (;;) {
	// While data request continue to come in serve them as fast as possible
	// by getting data ready while the other end is working
	char request = Serial.read();
	if (request == START_STREAM) {
	    while (Serial.read() != END_STREAM) {
		if (sample_count == 100)
		    sample_count = 0;
#if DEBUG
		print_data();
#else
		bluetooth_send();
#endif
		sample_count += 1;
	    }
	}
	else if (request == SEND_SINGLE) {
#if DEBUG
	    print_data();
#else
	    bluetooth_send();
#endif
	}
    }
}	    

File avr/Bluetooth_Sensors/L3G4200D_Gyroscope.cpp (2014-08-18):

// Writen by Peter Jeffris, University of Colorado Mechanical Engineering

// Class to provide an interface for the L3G4200D MEMS gyroscope rate sensor IC. The sensor
// hosts high and low pass filtering functions, power management and variable range. Output
// reflects the angular velocity or angular rate of the motion around its central axis.
// This device comunicates on I2C and can be attached to a common data bus with other
// inertial sensors.

#include "L3G4200D_Gyroscope.h"

// I2C address defined by the datasheet and jumper configuration
#define DEVICE_ADDRESS 0x69

// Register addresses from ST Datasheets
#define WHO_AM_I   0x0F
#define CTRL_REG1 0x20
#define CTRL_REG2 0x21
#define CTRL_REG3 0x22
#define CTRL_REG4 0x23
#define CTRL_REG5 0x24
#define REFERENCE 0x25
#define OUT_TEMP 0x26
#define STATUS_REG 0x27
#define OUT_X_L 0x28
#define OUT_X_H 0x29
#define OUT_Y_L 0x2A
#define OUT_Y_H 0x2B
#define OUT_Z_L 0x2C
#define OUT_Z_H 0x2D
#define FIFO_CTRL_REG 0x2E
#define FIFO_SRC_REG 0x2F

//Register values from ST datasheets
#define WHO_AM_I_VALUE 0xD3
#define ACTIVE 0x08
#define DISABLE_SLEEP 0x07
#define OUTPUT_800HZ 0xC0
#define OUTPUT_MASK 0x3F
#define BANDWIDTH_110HZ 0x30
#define BANDWIDTH_50HZ 0x20
#define BANDWIDTH_35HZ 0x10
#define BANDWIDTH_30HZ 0x00
#define BANDWIDTH_MASK 0xCF
#define FILTER_56HZ 0x00
#define FILTER_30HZ 0x01
#define FILTER_15HZ 0x02
#define FILTER_8HZ 0x03
#define FILTER_4HZ 0x04
#define FILTER_2HZ 0x05
#define FILTER_1HZ 0x06
#define FILTER_HALFHZ 0x07
#define FILTER_FIFTHHZ 0x08
#define FILTER_TENTHHZ 0x09
#define FILTER_MASK 0xF0
#define REBOOT 0x80
#define ENABLE_HP_FILTER 0x11
#define ENABLE_LP_FILTER 0x02
#define RANGE_200DPS 0x00
#define RANGE_500DPS 0x10
#define RANGE_2000DPS 0x20
#define RANGE_MASK 0x60


// Error handeling codes
#define NO_ERROR 0
#define BUFFER_SIZE_ERROR 1
#define ADDRESS_NO_ACKNOWLEDGE 2
#define DATA_NO_ACKNOWLEDGE 3
#define TWI_ERROR 4
#define IDENTIFICATION_FAILURE 5


// Initialization of the communication and sensor hardware
byte L3G4200D_Gyroscope::setup()
{
    // Setup the I2C library
    Wire.begin();

    // Register and error code state
    byte reg_value, error;

    // Check the identity register
    error = readRegister(DEVICE_ADDRESS, WHO_AM_I, reg_value);
    if (error != NO_ERROR)
	return error;

    // Stop if the identity for this address is incorrect
    if (reg_value != WHO_AM_I_VALUE)
    {
	error = IDENTIFICATION_FAILURE;
	return error;
    }

    // Power down the sampling hardware
    error = standby();
    if (error != NO_ERROR)
    	return error;

    // Reset all registers to default
    error = reset();
    if (error != NO_ERROR)
    	return error;

    // Get the main control state
    error = readRegister(DEVICE_ADDRESS, CTRL_REG1, reg_value);
    if (error != NO_ERROR)
    	return error;

    // Initialize with maximum sample rate
    reg_value = reg_value & OUTPUT_MASK;
    reg_value = reg_value | OUTPUT_800HZ;
    error = writeRegister(DEVICE_ADDRESS, CTRL_REG1, reg_value);
    if (error != NO_ERROR)
    	return error;

    // Activate sampling
    error = activate();
    return error;
}

// Activate sampling hardware amplifiers
byte L3G4200D_Gyroscope::activate()
{
    // Register and error code state
    byte reg_value, error;

    // Get control register state so settings are saved
    error = readRegister(DEVICE_ADDRESS, CTRL_REG1, reg_value);
    if (error != NO_ERROR)
	return error;

    // Flip the active state bit
    reg_value = reg_value | ACTIVE;
    error =  writeRegister(DEVICE_ADDRESS, CTRL_REG1, reg_value);
    return error;
}

// Turn off the sampling hardware
byte L3G4200D_Gyroscope::standby()
{
    // Register and error code state
    byte reg_value, error;

    // Get control register state to save setttings
    error = readRegister(DEVICE_ADDRESS, CTRL_REG1, reg_value);
    if (error != NO_ERROR)
	return error;

    // Send the active bit low
    reg_value = reg_value & ~ACTIVE;
    return writeRegister(DEVICE_ADDRESS, CTRL_REG1, reg_value); 
}

// Reset all settings and data values
byte L3G4200D_Gyroscope::reset()
{
    // Register and error code state
    byte reg_value, error;

    // Set the reboot flag high, it will automatically clear
    reg_value = REBOOT;
    error =  writeRegister(DEVICE_ADDRESS, CTRL_REG5, reg_value);
    return error;
}

// Set the upper and lower range to be measured in degrees per second defined by a range
// code enumeration
byte L3G4200D_Gyroscope::setRange(range max_range)
{
    // Register and error code state
    byte reg_value, error;

    // Get the current settings state
    error = readRegister(DEVICE_ADDRESS, CTRL_REG4, reg_value);
    if (error != NO_ERROR)
	return error;

    // Set the range bits based in the masked range
    reg_value = reg_value & RANGE_MASK;
    reg_value = reg_value | max_range;
    error = writeRegister(DEVICE_ADDRESS, CTRL_REG4, reg_value);
    return error;
}

// Enable mode to turn off the sampling hardware power if no requests are
// recived within a short timeout period
byte L3G4200D_Gyroscope::enableSleep()
{
    // Register and error code state
    byte reg_value, error;

    // Get the current state of the control register to save the settings
    error = readRegister(DEVICE_ADDRESS, CTRL_REG1, reg_value);
    if (error != NO_ERROR)
	return error;

    // Set the sleep bit low
    reg_value = reg_value & ~DISABLE_SLEEP; 
    error = writeRegister(DEVICE_ADDRESS, CTRL_REG1, reg_value); 
    return error; 
}

// Disable sleep mode for responsive sampling at the expense of incresed power consumption
byte L3G4200D_Gyroscope::disableSleep()
{
    // Register and error code state
    byte reg_value, error;

    // Get the current settings
    error = readRegister(DEVICE_ADDRESS, CTRL_REG1, reg_value);
    if (error != NO_ERROR)
	return error;

    // Set the sleep bit high
    reg_value = reg_value | DISABLE_SLEEP;
    error = writeRegister(DEVICE_ADDRESS, CTRL_REG1, reg_value);
    return error;
}

// Enable high pass filtering on the output
byte L3G4200D_Gyroscope::enableHighPassFilter()
{
    // Register and error code state
    byte reg_value, error;

    // Save the current register values
    error = readRegister(DEVICE_ADDRESS, CTRL_REG5, reg_value);
    if (error != NO_ERROR)
	return error;

    // Set the high pass flag high
    reg_value = reg_value | ENABLE_HP_FILTER;
    error = writeRegister(DEVICE_ADDRESS, CTRL_REG5, reg_value);
    return error; 
}

// Disable high pass filtering of the output
byte L3G4200D_Gyroscope::disableHighPassFilter()
{
    // Register and error code state
    byte reg_value, error;

    // Save the previous register states
    error = readRegister(DEVICE_ADDRESS, CTRL_REG5, reg_value);
    if (error != NO_ERROR)
	return error;

    // Set the high pass flag low
    reg_value = reg_value & ~ENABLE_HP_FILTER;
    error = writeRegister(DEVICE_ADDRESS, CTRL_REG5, reg_value);
    return error; 
}
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

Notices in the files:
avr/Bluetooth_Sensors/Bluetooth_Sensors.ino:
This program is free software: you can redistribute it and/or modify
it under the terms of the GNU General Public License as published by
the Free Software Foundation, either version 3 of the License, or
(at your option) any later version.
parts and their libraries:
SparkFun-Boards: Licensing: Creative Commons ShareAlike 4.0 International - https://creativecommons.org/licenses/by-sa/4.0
